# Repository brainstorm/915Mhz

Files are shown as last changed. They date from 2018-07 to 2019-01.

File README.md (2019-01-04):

# 915Mhz RF filter breakout boards

This is an experiment with a 915Mhz LoRa module and SAW filters as a substitute for discrete components. The original *raison d'être* of this repository is my personal outrage after seeing the following **$100 evaluation board** for the [PE4259](https://www.psemi.com/pdf/datasheets/pe4259ds.pdf):

<p align="center">
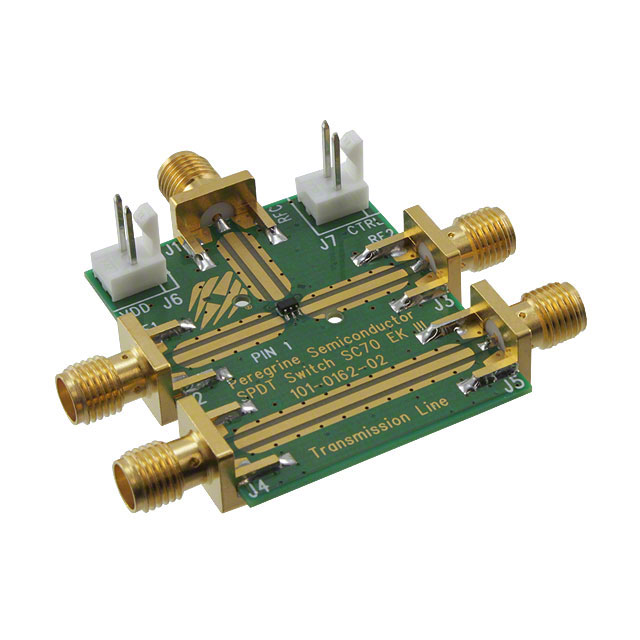
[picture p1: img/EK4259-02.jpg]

</p>

And indeed, [AppliedCarbon from OSHPark also thought so and designed a smaller PCB](https://oshpark.com/shared_projects/2MRloEFC).

Gold tracks and pads, many vias and proper RF engineering, sure, but $100 plus shipping? Let's see how the homemade way works in comparison? On the **`master`** branch of this repository, I'm putting together a board with the RF switch and the SAW filter (will be using a 915 Mhz [sf2098e "low insertion loss" SAW filter](https://wireless.murata.com/RFM/data/sf2098e.pdf), no frills design for now. I might put the vias in place if needed in the future and compare performance/loss and the accompanying [S parameters](https://en.wikipedia.org/wiki/Scattering_parameters).

<p align="center">
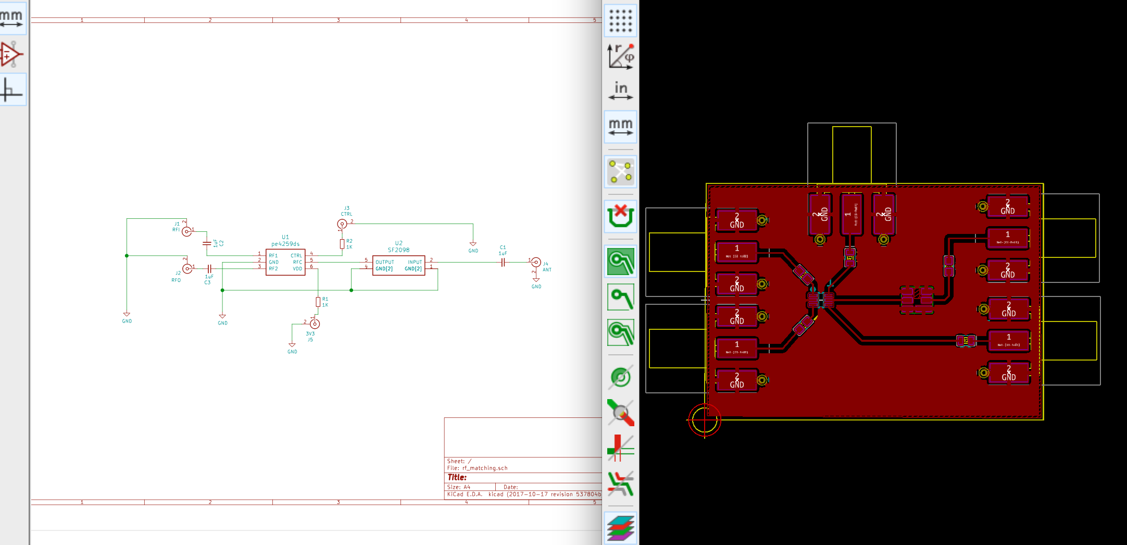
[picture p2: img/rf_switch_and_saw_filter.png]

</p>

But since the approach above might not be modular enough for my testing purposes (thanks Chris), I've forked that layout into two branches:

```bash
$ git branch -a
* master
  rf_switch_only
  saw_filter_only
```

Here's how each of those look like at the moment of writing this, let's play "spot the differences", shall we?:

<p align="center">
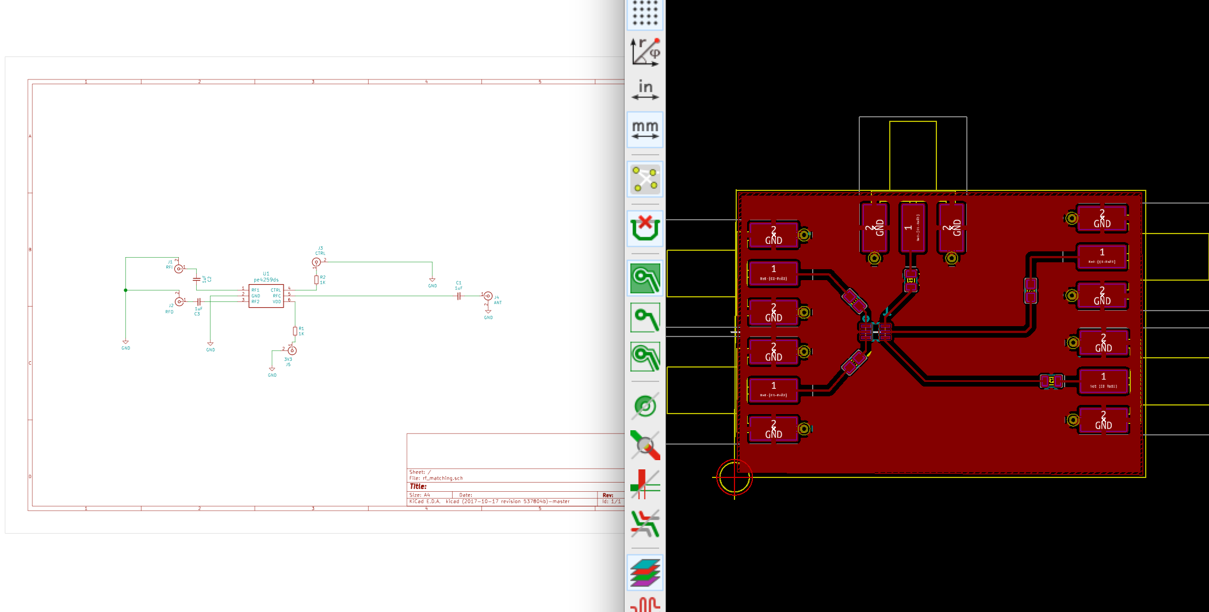
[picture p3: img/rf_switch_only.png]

</p>

<p align="center">
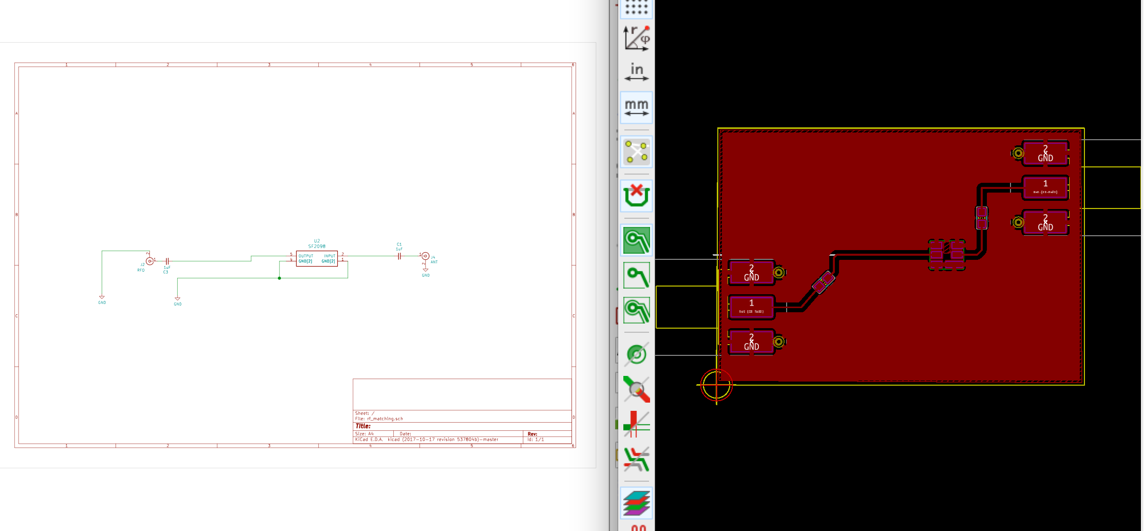
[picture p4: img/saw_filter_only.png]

</p>

Now, as with the [Instructables Carvey Board project](https://github.com/brainstorm/carvey_board), I've generated some G-Code (under the **homefab** subdirectory) with [FlatCam](http://flatcam.org/) to carve those board at home, wish me luck with the spectrum analyzers and followup testing!

Alternatively, there's a .zip under homefab, containing the ready-to-send gerbers to i.e Seed Studios or any other PCB manufacturer. Here's the latest iteration of the rf matching board on `master`:

<p align="center">
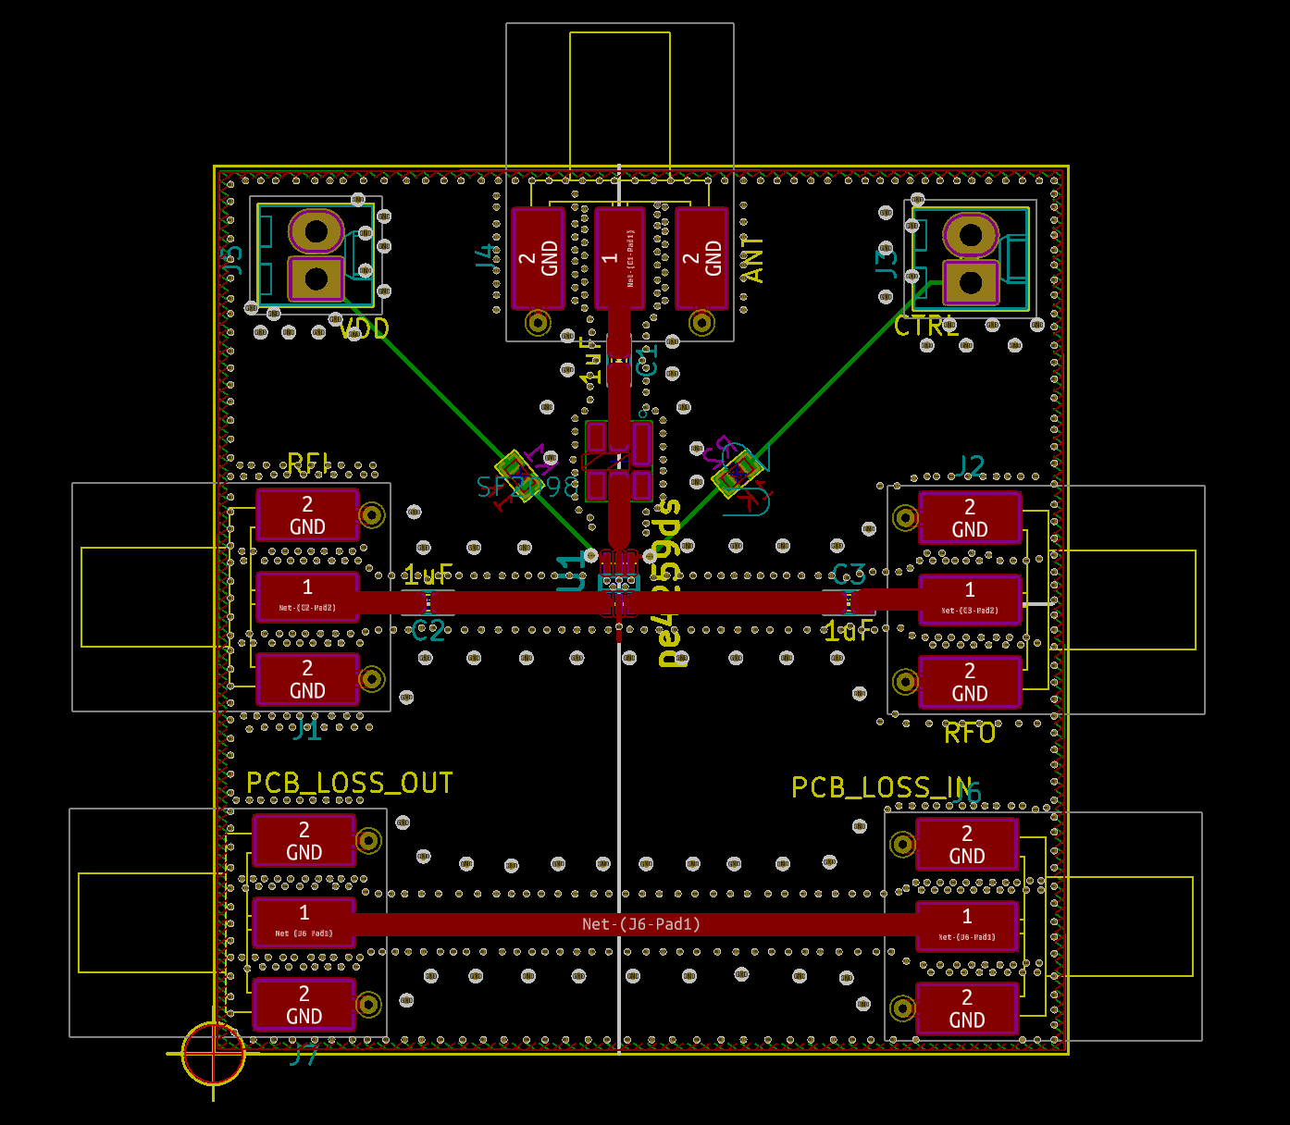
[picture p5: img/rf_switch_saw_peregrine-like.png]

</p>

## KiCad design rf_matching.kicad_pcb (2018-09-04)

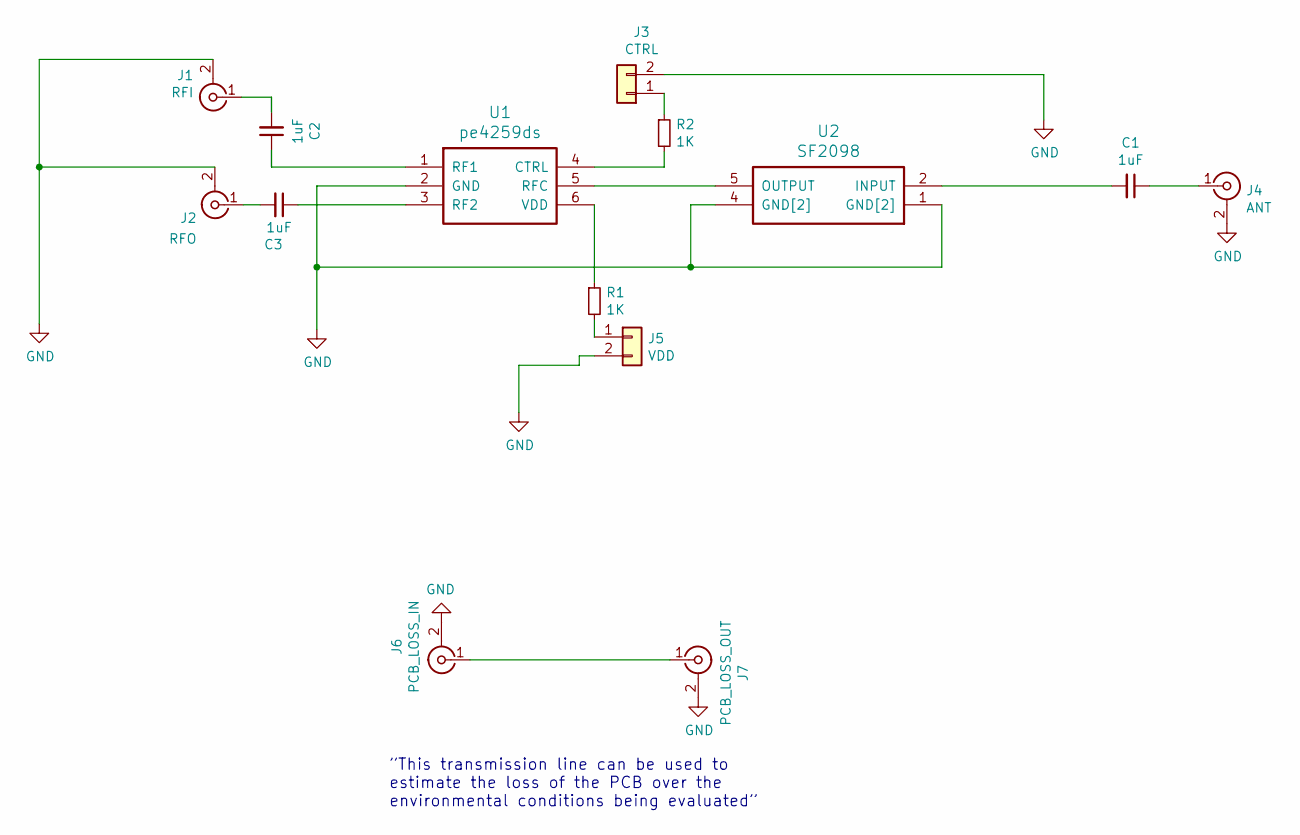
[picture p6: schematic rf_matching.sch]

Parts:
C1, C2, C3: 1uF; C_0603
J1: RFI; Molex_SMA_Jack_Edge_Mount
J2: RFO; Molex_SMA_Jack_Edge_Mount
J3: CTRL; Molex_KK-6410-02_02x2.54mm_Straight
J4: ANT; Molex_SMA_Jack_Edge_Mount
J5: VDD; Molex_KK-6410-02_02x2.54mm_Straight
J6: PCB_LOSS_IN; Molex_SMA_Jack_Edge_Mount
J7: PCB_LOSS_OUT; Molex_SMA_Jack_Edge_Mount
R1, R2: 1K; R_0603
U1: pe4259ds; SC70-6_Pitch-0.65_2.00x2.10x1.00mm
U2: SF2098; SON120P300X300X110-6N

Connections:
GND: J1.2 (Ext), J2.2 (Ext), J3.2, J4.2 (Ext), J5.2, J6.2 (Ext), J7.2 (Ext), U1.2 (GND), U2.1 (GND[2]), U2.3 (GND[2]), U2.4 (GND[2]), U2.6 (GND[2])
unnamed: C1.1, J4.1 (In)
unnamed: C1.2, U2.2 (INPUT)
unnamed: C2.1, U1.1 (RF1)
unnamed: C2.2, J1.1 (In)
unnamed: C3.1, U1.3 (RF2)
unnamed: C3.2, J2.1 (In)
unnamed: J3.1, R2.1
unnamed: J5.1, R1.2
unnamed: J6.1 (In), J7.1 (In)
unnamed: R1.1, U1.6 (VDD)
unnamed: R2.2, U1.4 (CTRL)
unnamed: U1.5 (RFC), U2.5 (OUTPUT)

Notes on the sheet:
”This transmission line can be used to estimate the loss of the PCB over the environmental conditions being evaluated”

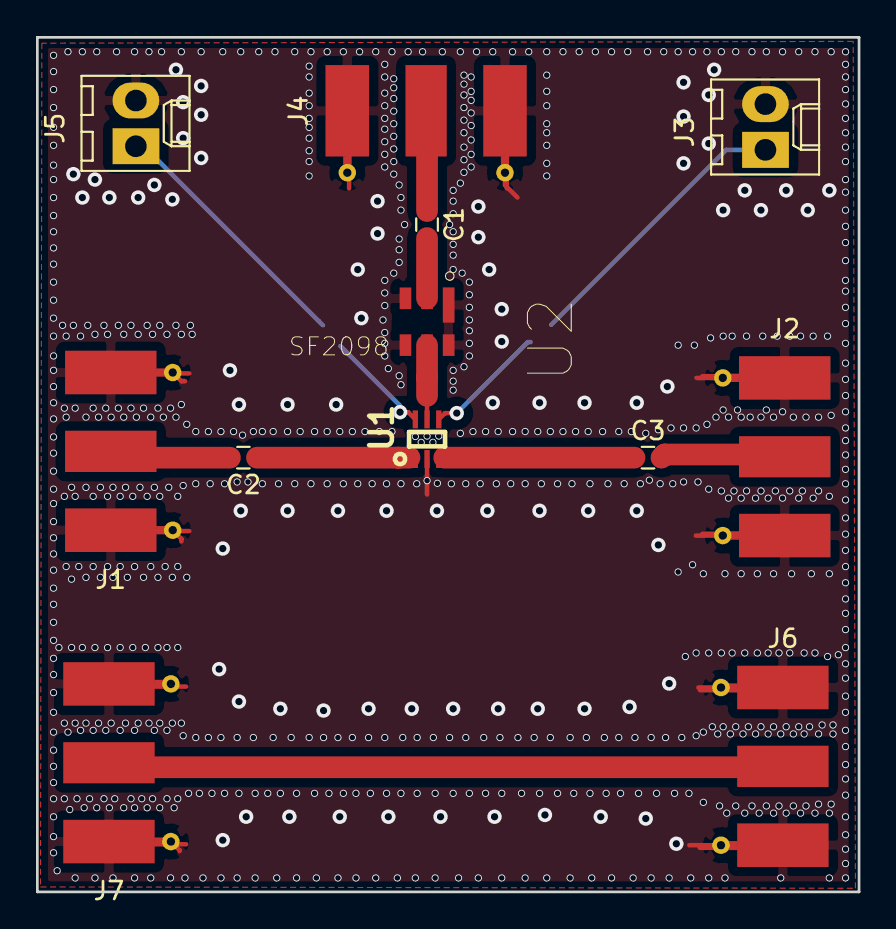
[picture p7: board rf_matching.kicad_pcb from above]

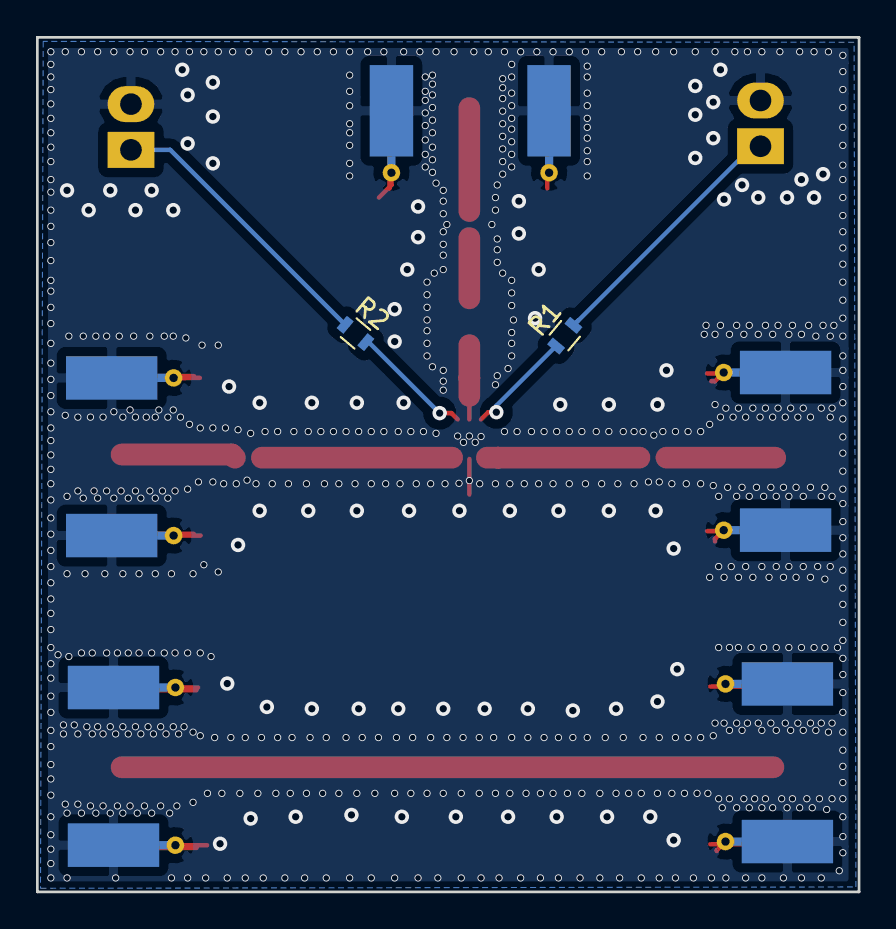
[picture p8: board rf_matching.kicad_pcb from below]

Board: 2 copper layers, 45.7 x 47.5 mm, 14 parts (2 on the bottom side), 13 nets.

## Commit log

2018-07-22 Initial RF switch and SAW filter layout
    [pe4259ds.csv, rf_matching.kicad_pcb, rf_matching.sch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]
2018-07-22 Fixing ground plane dubiously through the connectors, sparing a link and going single layer... will it work/perform well?
    [rf_matching.kicad_pcb]
2018-07-22 Add gerbers and gcode for the combined rf switch and SAW filter board
    [rf_matching.kicad_pcb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]
2018-07-24 Update board isolation and cutout g-code so that it complies with Easel restrictions: https://inventables.desk.com/customer/portal/articles/2258567-easel-g-code-spec
    [rf_matching.kicad_pcb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]
2018-09-01 Add thicker bias, add PCB LOSS line
    [rf_matching.kicad_pcb, rf_matching.sch]
2018-09-04 Redesign, more similar to official evaluation board
    [rf_matching.kicad_pcb, rf_matching.sch]
2018-09-04 Add by-hand vias, silly semi-random placement
    [rf_matching.kicad_pcb]
2018-09-04 Add current iteration image, boards sent to Seed Studios via promotion pricing: https://twitter.com/braincode/status/1036909730244034560
    [rf_matching-B.Cu.gbl, rf_matching-B.Mask.gbs, rf_matching-B.SilkS.gbo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]
